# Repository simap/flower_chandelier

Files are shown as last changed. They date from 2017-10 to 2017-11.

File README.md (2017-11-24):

# flower chandelier

assembled

svg for laser cutting

3d printed mount

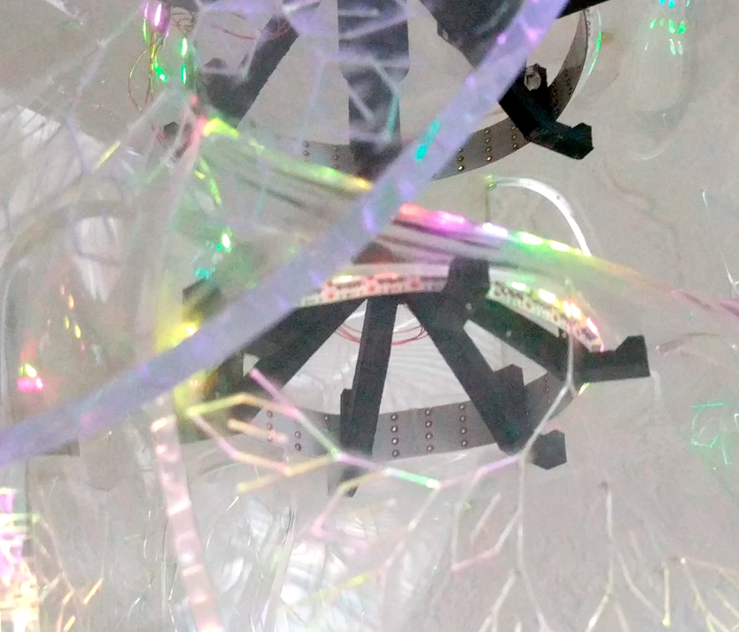
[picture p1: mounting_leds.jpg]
mounting leds closeup


## Instructions

1. Laser cut the tulip pattern. You can scale it as necessary for different sizes or insets. I set the tree fractal to a weak cut setting that wouldn't go more than 1-2mm.
2. Optionally cut 2 wood discs a bit larger to make a vise while heat-bending the petals. You can use a bolt to keep them together.
3. Heat and bend the petals as desired. Depending on the size of inserts, the angle might need to be adjusted.
4. Measure the holes, and use the tulip mount.scad to 3D model mounts for each petal layer. It can make tops, middles and bottoms which thread together.
5. Cut and wire up some LED strips to fit, the printed mount should keep the LEDs snug against the edge.
6. First counter-wind so that the LED wiring doesn't get wrapped up, then thread each segment together.

If you're looking for an excellent LED controller pairing with this setup, check out [Pixelblaze](https://bhencke.com/pixelblaze)! 😀

You can check out my [assembled chandelier here](https://www.bhencke.com/blog/2017/7/13/laser-cut-led-flower-chandelier)

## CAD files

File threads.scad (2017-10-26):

/*
 * ISO-standard metric threads, following this specification:
 *          http://en.wikipedia.org/wiki/ISO_metric_screw_thread
 *
 * Dan Kirshner - dan_kirshner@yahoo.com
 *
 * You are welcome to make free use of this software.  Retention of my
 * authorship credit would be appreciated.
 *
 * Version 1.9.  2016-07-03  Option: tapered.
 * Version 1.8.  2016-01-08  Option: (non-standard) angle.
 * Version 1.7.  2015-11-28  Larger x-increment - for small-diameters.
 * Version 1.6.  2015-09-01  Options: square threads, rectangular threads.
 * Version 1.5.  2015-06-12  Options: thread_size, groove.
 * Version 1.4.  2014-10-17  Use "faces" instead of "triangles" for polyhedron
 * Version 1.3.  2013-12-01  Correct loop over turns -- don't have early cut-off
 * Version 1.2.  2012-09-09  Use discrete polyhedra rather than linear_extrude ()
 * Version 1.1.  2012-09-07  Corrected to right-hand threads!
 */

// Examples.
//
// Standard M8 x 1.
// metric_thread (diameter=8, pitch=1, length=4);

// Square thread.
// metric_thread (diameter=8, pitch=1, length=4, square=true);

// Non-standard: long pitch, same thread size.
//metric_thread (diameter=8, pitch=4, length=4, thread_size=1, groove=true);

// Non-standard: 20 mm diameter, long pitch, square "trough" width 3 mm,
// depth 1 mm.
//metric_thread (diameter=20, pitch=8, length=16, square=true, thread_size=6, 
//               groove=true, rectangle=0.333);

// English: 1/4 x 20.
//english_thread (diameter=1/4, threads_per_inch=20, length=1);

// Tapered.  Example -- pipe size 3/4" -- per:
// http://www.engineeringtoolbox.com/npt-national-pipe-taper-threads-d_750.html
// english_thread (diameter=1.05, threads_per_inch=14, length=3/4, taper=1/16);

// Thread for mounting on Rohloff hub.
//difference () {
//   cylinder (r=20, h=10, $fn=100);
//
//   metric_thread (diameter=34, pitch=1, length=10, internal=true, n_starts=6);
//}


// ----------------------------------------------------------------------------
function segments (diameter) = min (50, ceil (diameter*6));


// ----------------------------------------------------------------------------
// internal -    true = clearances for internal thread (e.g., a nut).
//               false = clearances for external thread (e.g., a bolt).
//               (Internal threads should be "cut out" from a solid using
//               difference ()).
// n_starts -    Number of thread starts (e.g., DNA, a "double helix," has
//               n_starts=2).  See wikipedia Screw_thread.
// thread_size - (non-standard) size of a single thread "V" - independent of
//               pitch.  Default: same as pitch.
// groove      - (non-standard) subtract inverted "V" from cylinder (rather than
//               add protruding "V" to cylinder).
// square      - Square threads (per
//               https://en.wikipedia.org/wiki/Square_thread_form).
// rectangle   - (non-standard) "Rectangular" thread - ratio depth/width
//               Default: 1 (square).
// angle       - (non-standard) angle (deg) of thread side from perpendicular to
//               axis (default = standard = 30 degrees).
// taper       - diameter change per length (National Pipe Thread/ANSI B1.20.1
//               is 1" diameter per 16" length).
module metric_thread (diameter=8, pitch=1, length=1, internal=false, n_starts=1,
                      thread_size=-1, groove=false, square=false, rectangle=0,
                      angle=30, taper=0)
{
   // thread_size: size of thread "V" different than travel per turn (pitch).
   // Default: same as pitch.
   local_thread_size = thread_size == -1 ? pitch : thread_size;
   local_rectangle = rectangle ? rectangle : 1;

   n_segments = segments (diameter);
   h = (square || rectangle) ? local_thread_size*local_rectangle/2 : local_thread_size * cos (angle);

   h_fac1 = (square || rectangle) ? 0.90 : 0.625;

   // External thread includes additional relief.
   h_fac2 = (square || rectangle) ? 0.95 : 5.3/8;

   if (! groove) {
      metric_thread_turns (diameter, pitch, length, internal, n_starts,
                           local_thread_size, groove, square, rectangle, angle,
                           taper);
   }

   difference () {

      // Solid center, including Dmin truncation.
      tapered_diameter = diameter - length*taper;
      if (groove) {
         cylinder (r1=diameter/2, r2=tapered_diameter/2,
                   h=length, $fn=n_segments);
      } else if (internal) {
         cylinder (r1=diameter/2 - h*h_fac1, r2=tapered_diameter/2 - h*h_fac1,
                   h=length, $fn=n_segments);
      } else {

         // External thread.
         cylinder (r1=diameter/2 - h*h_fac2, r2=tapered_diameter/2 - h*h_fac2,
                   h=length, $fn=n_segments);
      }

      if (groove) {
         metric_thread_turns (diameter, pitch, length, internal, n_starts,
                              local_thread_size, groove, square, rectangle,
                              angle, taper);
      }
   }
}


// ----------------------------------------------------------------------------
// Input units in inches.
// Note: units of measure in drawing are mm!
module english_thread (diameter=0.25, threads_per_inch=20, length=1,
                      internal=false, n_starts=1, thread_size=-1, groove=false,
                      square=false, rectangle=0, angle=30, taper=0)
{
   // Convert to mm.
   mm_diameter = diameter*25.4;
   mm_pitch = (1.0/threads_per_inch)*25.4;
   mm_length = length*25.4;

   echo (str ("mm_diameter: ", mm_diameter));
   echo (str ("mm_pitch: ", mm_pitch));
   echo (str ("mm_length: ", mm_length));
   metric_thread (mm_diameter, mm_pitch, mm_length, internal, n_starts, 
                  thread_size, groove, square, rectangle, angle, taper);
}

// ----------------------------------------------------------------------------
module metric_thread_turns (diameter, pitch, length, internal, n_starts, 
                            thread_size, groove, square, rectangle, angle,
                            taper)
{
   // Number of turns needed.
   n_turns = floor (length/pitch);

   intersection () {

      // Start one below z = 0.  Gives an extra turn at each end.
      for (i=[-1*n_starts : n_turns+1]) {
         translate ([0, 0, i*pitch]) {
            metric_thread_turn (diameter, pitch, internal, n_starts, 
                                thread_size, groove, square, rectangle, angle,
                                taper, i*pitch);
         }
      }

      // Cut to length.
      translate ([0, 0, length/2]) {
         cube ([diameter*3, diameter*3, length], center=true);
      }
   }
}


// ----------------------------------------------------------------------------
module metric_thread_turn (diameter, pitch, internal, n_starts, thread_size,
                           groove, square, rectangle, angle, taper, z)
{
   n_segments = segments (diameter);
   fraction_circle = 1.0/n_segments;
   for (i=[0 : n_segments-1]) {
      rotate ([0, 0, i*360*fraction_circle]) {
         translate ([0, 0, i*n_starts*pitch*fraction_circle]) {
            current_diameter = diameter - taper*(z + i*n_starts*pitch*fraction_circle);
            thread_polyhedron (current_diameter/2, pitch, internal, n_starts, 
                               thread_size, groove, square, rectangle, angle);
         }
      }
   }
}


// ----------------------------------------------------------------------------
// z (see diagram) as function of current radius.
// (Only good for first half-pitch.)
function z_fct (current_radius, radius, pitch, angle)
   = 0.5* (current_radius - (radius - 0.875*pitch*cos (angle)))
                                                       /cos (angle);

// ----------------------------------------------------------------------------
module thread_polyhedron (radius, pitch, internal, n_starts, thread_size,
                          groove, square, rectangle, angle)
{
   n_segments = segments (radius*2);
   fraction_circle = 1.0/n_segments;

   local_rectangle = rectangle ? rectangle : 1;

   h = (square || rectangle) ? thread_size*local_rectangle/2 : thread_size * cos (angle);
   outer_r = radius + (internal ? h/20 : 0); // Adds internal relief.
   //echo (str ("outer_r: ", outer_r));

   // A little extra on square thread -- make sure overlaps cylinder.
   h_fac1 = (square || rectangle) ? 1.1 : 0.875;
   inner_r = radius - h*h_fac1; // Does NOT do Dmin_truncation - do later with
                                // cylinder.

   translate_y = groove ? outer_r + inner_r : 0;
   reflect_x   = groove ? 1 : 0;

   // Make these just slightly bigger (keep in proportion) so polyhedra will
   // overlap.
   x_incr_outer = (! groove ? outer_r : inner_r) * fraction_circle * 2 * PI * 1.02;
   x_incr_inner = (! groove ? inner_r : outer_r) * fraction_circle * 2 * PI * 1.02;
   z_incr = n_starts * pitch * fraction_circle * 1.005;

   /*
    (angles x0 and x3 inner are actually 60 deg)
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

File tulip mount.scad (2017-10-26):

include <threads.scad>;

d1 = 73;
d2 = 88;
pitch = 6;
threadD = 10;
threadScaleFactor = .91; //helps threads fit 
mountR = threadD/2+2;
arms = 6;

//top
mount(d=d2, bottom=true, arms=arms);

//bottom
translate([100,0,0])
mount(d=d1, bottom=false, boltH = 30, arms=arms);


//a middle-section would look like this:
//mount(d2, true, 30);

module mount(d, bottom = false, boltH = 0, arms=6) {
    armT = 5;
    r = d/2;
    h = sqrt(d*d)/2;
    difference() {
        union() {
            offset = bottom ? [0,0,0] : [0,0,h - threadD/2 - 5];
            ch = bottom ? h : 10;
            translate(offset)
            cylinder(r=mountR,h=ch, $fs=.5);
            //rotate([0,0,360/12])
            ringHolder(d/2,armT, arms);

            translate([0,0,h]) {
                if (boltH > 0) {
                    bolt(mountR, boltH);
                } else {
                    loop();
                }
            }
        }
        
        if (bottom) {
            translate([0,0,-.01])
            metric_thread(threadD, pitch, min(20,h/2), internal=true, thread_size=2);
        }
    }
}

module loop() {
    rotate([90,0,0])
    rotate_extrude(angle=180, $fs=.5)
    translate([4, 0, 0])
    circle(r = 2);
    
}

module bolt(r, boltH) {
    
    ch = boltH > 20 ? boltH - 20 : 0;
    boltH = boltH - ch;

    cylinder(r=r,h=ch, $fs=.5);
    translate([0,0,ch]) {
    scale([threadScaleFactor, threadScaleFactor, 1])
    metric_thread(threadD, pitch, boltH, internal=false, thread_size=2);
    }
}

module ringHolder(r, h, arms) {
    
    translate([0,0,6])
    difference() {
        for (i = [0:1:arms]) {
            a = 360/arms * i;
            l = sqrt(2*r*r);
            
            rotate([0,0,a])
            translate([r-2,0,-2.5])
            rotate([0,-90,180])
            //translate([0,0,0])
            clip();
            
            
            translate([0,0,r-12.5])
            rotate([0,45,a]) {
                translate([0,-h/2, -h/25])
                cube([l-6,h,h]);
            }
        }
        #ring(r,h);
        translate([0,0,-11]) cube([r*3,r*3,10], center=true);
    }
}

module ring(r, h, t=10) {
    difference() {
        cylinder(r = r + 10, h=h);
        translate([0,0,-.01])
        cylinder(r = r, h=h + 0.02);
    }
}


module clip() {
    
    $fn = 100;

    sheetT = 5; //6.35 for 1/2"
    pinR = 3/2;
    stripW = 10;
    stripT = .5;
    ledW = 6;
    ledH = 2;

    t = 3.5;
    tolerance = 0.2;

    backL = stripW + t*2;
    backW = 5;
    backT = t;

    mountW = 5;
    mountL = 7;

    spacerW = (stripW-sheetT)/2;

    //back
    //translate([-t,-backW/2,-stripT-backT])
    //cube([backL, backW, backT]);
    
    translate([-t,0 ,-stripT-1.5])
    rotate([0,90,0])
    union() {
        cylinder(r=1.5,h=backL, $fn=20);    
        translate([-t + backT,-backW/2,0])
        cube([3,backW,backL]);
    }

    for (i = [0:0]) {
        rotate([0,0,180*i]) {
            translate([-stripW*i,0,0]) {
                //arm
                translate([-t,-backW/2,-stripT-1.5-backT/2])
                cube([t, backW, backT+1.5+stripT+ledH]);

                //mount surface
                translate([-t,-mountW/2,ledH])
                difference() {
                    cube([spacerW+backT, mountW, ledH-ledH+mountL]);
                    translate([1.5,0,0])
                    rotate([0,45,0])
                    cube([spacerW+backT, mountW, ledH-ledH+mountL]);
                }
            }
        }
    }
}

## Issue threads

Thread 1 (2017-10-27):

Link to Pixelblaze

beroe, 2017-10-27:
Hi.
The current link to https://www.bhencke.com/pixelblaze is a relative link, so gets pre-pended with the github info and fails...
I'd love to see a bit more about how the LEDs are connected to the mount. Can't quite visualize it.
Very nice project..!

simap, 2017-11-24:
@beroe , thanks for the heads-up!
The LEDs are looped around the mount, and rest on the edge, facing outward. The strips have sticky back, which helps, but I also tack them down with some heat glue.

simap, 2017-11-24:
@beroe
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

Closed 2017-11-24.

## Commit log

2017-10-26 tulip chandelier files
    [threads.scad, tulip mount.scad]
2017-10-26 note about tree fractal laser
2017-11-24 add closeup image of LED mounts
